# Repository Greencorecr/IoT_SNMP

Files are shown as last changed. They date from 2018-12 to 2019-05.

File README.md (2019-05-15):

# IoT_SNMP 
Dispositivos con The Things Network para conectar a SNMP

## [Conector con MQTT](https://github.com/Greencorecr/IoT_SNMP/tree/master/software/ttn2db)

Se mantiene un daemon escuchando en la plataforma de MQTT de TheThingsNetwork, escuchando mensajes de los diferentes sensores, y guardando en una base de datos de InfluxDB en formato JSON, los valores decodificados que recibe, así como un timestamp del momento en el que recibe el mensaje.

## [Conector con SNMP](https://github.com/Greencorecr/IoT_SNMP/tree/master/software/SNMP)

Dependiendo del OID consultado, snmpd llama al conector que saca de la base de el valor del sensor, así como verificando que el timestamp no sea más viejo que 5 minutos, lo que quiere decir que el sensor ha dejado de comunicarse, en el caso en que retorna "0" como valor del sensor. Se utiliza la técnica de este [ejemplo](https://github.com/fede2cr/raspberry-pi_snmp/blob/master/snmpd-example/snmpd.conf)

## Sensores

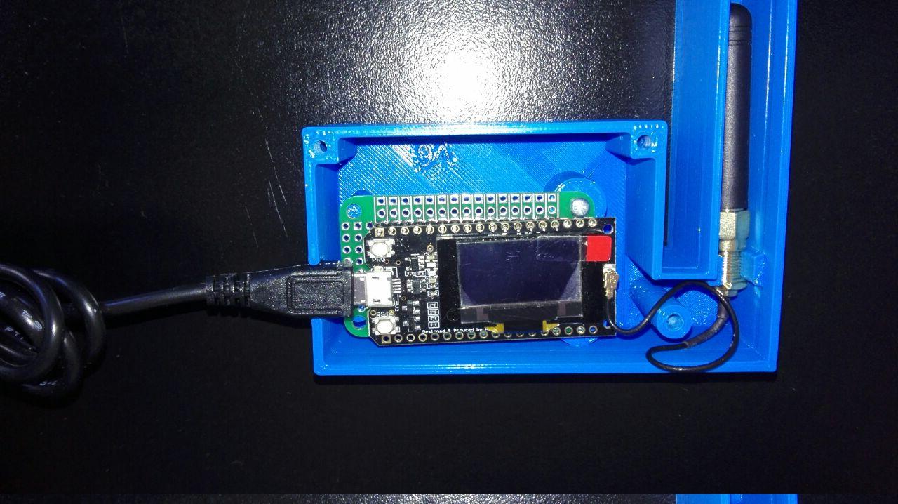
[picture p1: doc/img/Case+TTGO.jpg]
Case con TTGO


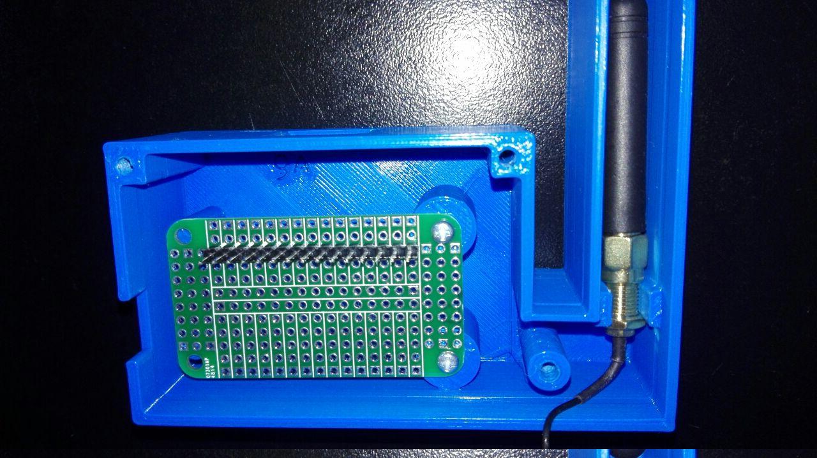
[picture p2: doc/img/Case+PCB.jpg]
Case con PCB Case con TTGO


- [Sensor de Consumo eléctrico](https://github.com/Greencorecr/IoT_SNMP/tree/master/firmware/Amperaje)
- [Sensor de Caída eléctrica](https://github.com/Greencorecr/IoT_SNMP/tree/master/firmware/Caida)
- [Sensor de Gotas](https://github.com/Greencorecr/IoT_SNMP/tree/master/firmware/Gotas)
- [Sensor de Temperatura y Humedad](https://github.com/Greencorecr/IoT_SNMP/tree/master/firmware/TempHum)
- [Sensor de Puerta](https://github.com/Greencorecr/IoT_SNMP/tree/master/firmware/Puerta)

## Arduino IDE

### Dependencias:

- Paquetes necesarios para Ubuntu

```
sudo apt update
sudo apt install -y python2 python2-pip
sudo python2 -m pip install pyserial
```

### Librerías:
- Instalar IBM LMIC framework by IBM Version 1.5.0+arduino-2

  Se debe modificar el archivo ``Arduino/libraries/IBM_LMIC_framework/src/lmic/config.h``, comentando la primera línea y descomentando la segunda:

```
  //#define CFG_eu868 1
  #define CFG_us915 1
```
- Instalar DHT sensor library for ESPx by beegee_tokyo Version 1.0.9
- Instalar U8g2 by oliver Version 2.25.10
- Instalar [Arduino_SNMP](https://github.com/fede2cr/Arduino_SNMP) en su carpera de liberías de Arduino, como puede ser ``Arduino/libraries/``
- Instalar EasyButto by Evert Arias, Version 1.0.1

### Tarjetas/Boards

- Incluir en File -> Preferences -> Additional Boards Manager URLs: ``https://dl.espressif.com/dl/package_esp32_index.json``

- Instalar en Tool -> Board -> Board Manager: esp32 by Espressif Systems

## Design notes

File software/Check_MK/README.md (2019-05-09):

# Check_MK

## Descripción

El script de python ``db2snmp.py``, lee de una base de datos InfluxDB la cual ha sido alimentada por ``ttn2db.py``, y exporta según el valor consultado en formato de SNMP. Desde el servidor de monitoreo se debe configurar un chequeo para que consulte la información de los sensores vía SNMP, y la asocie con un servicio nuevo a monitorear.

## Instrucciones de configuración

### 1. Haber realizado la configuración del conector SNMP, y que la consulta por snmpwalk retorne datos reales.

TTN_SNMP/Conectores/SNMP/README.md

### 2. Crear un script de chequeo local:

```
sudo vim /opt/omd/sites/pruebas/local/share/check_mk/checks/sensor01_humedad
```

```
#!/usr/bin/python

def inventory_sensor01_humedad(info):
   inventory = []
   for line in info:
        tipo = line[0]
        valor = line[1]
        inventory.append((tipo, valor))
   # Debug, habilitarlo únicamente para validar el check local, ya que si se deja descomentado da un error cuando Check_MK Web escanea los servicios
   #print inventory
   return inventory

def check_sensor01_humedad(item, _no_params, info):
   for line in info:
        tipo = line[0]
        valor = line[1]
        if tipo == "humedad" and valor != "0" and valor != "12336":
           infotext = "humedad actual: " + valor
           return 0, infotext, [ ("humedad", valor) ]
        else:
           infotext = "humedad actual: " + valor
           return 2, infotext, [ ("humedad", valor) ]

check_info["sensor01_humedad"] = {
    "check_function"        : check_sensor01_humedad,
    "inventory_function"    : inventory_sensor01_humedad,
    "service_description"   : "Sensor",
    "snmp_info"             : ( ".1.3.6.1.4.1.8072.1.3.2.4.1.2.16.115.101.110.115.111.114.48.49.45.104.117.109.101.100.97.100", [ "1", "2" ] ) ,
    "has_perfdata"          : True,
}
```

### 3. Agregar el host a monitorear

Se debe agregar el host a monitorear (Raspberry Pi) con la correspondiente contraseña SNMP Community y sin monitoreo por agente, con el fin de que comience a escanear servicios a nivel de SNMP únicamente.

### 4. Validar chequeo local
Una vez agregado el host, ejecutar el siguiente comando para validar el chequeo local, para lo cual es necesario convertirse en el usuario propietario del sitio a nivel de OMD, en el siguiente ejemplo se asume que el sitio de Check_MK se llama "pruebas" y el host "raspberry"

``` 
sudo su - pruebas
```

```
OMD[pruebas]:~$ check_mk -v --checks sensor01_humedad -I raspberry

Discovering services on: raspberry
raspberry:
+ FETCHING DATA
 [snmp] Execute data source
 [piggyback] Execute data source
+ EXECUTING DISCOVERY PLUGINS (1)
[(u'humedad', u'52')]
SUCCESS - Found nothing new
```

Si el comando anterior funciona correctamente e imprime los datos recolectados, ejecutamos el siguiente comando para hacer un chequeo real:

```
OMD[pruebas]:~$ cmk --no-cache -nv raspberry
Check_MK version 1.5.0p9
+ FETCHING DATA
 [snmp] Execute data source
 [piggyback] Execute data source
CPU load             OK - 15 min load 0.08
CPU utilization      OK - 5.0% used
...
...
SNMP Info            OK - Linux raspberry 4.14.79-v7+ #1159 SMP Sun Nov 4 17:50:20 GMT 2018 armv7l, raspberry, Unknown, root
Sensor humedad       OK - humedad actual: 52
...

```

En este punto el chequeo local es funcional, por lo cual desde la interfaz web de Check_MK se puede observar como un nuevo servicio monitoreado.

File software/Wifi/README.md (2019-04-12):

# WIFI

## Descripción
La siguiente guía tiene como finalidad configurar la Raspberry Pi como Access Point y servidor DHCP, con el fin de que los sensores la utilicen para conectarse de forma inalámbrica para poder tener 2 métodos de comunicación para enviar sus datos (TTN y mediante SNMP vía wifi).

## Procedimiento de configuración de Access Point con servidor DHCP sobre Raspberry Pi

1. Instalar software para Access Point y servidor DHCP

	**sudo apt install hostapd isc-dhcp-server**

2. Configurar interfaces de red:

	**sudo vim /etc/network/interfaces**
	
	```
	auto eth0
	iface eth0 inet dhcp
	
	auto wlan0
	allow-hotplug wlan0
	iface wlan0 inet static
	  address 10.42.66.1
	  netmask 255.255.255.0
	```

3. Configurar interfaz de red para el servidor DHCP

	**sudo vim /etc/default/isc-dhcp-server**
	
	```
	INTERFACESv4="wlan0"
	```

4. Configurar servidor DHCP

	**sudo vim /etc/dhcp/dhcpd.conf**
	
	```
	option domain-name "localdomain.com";
	default-lease-time 600;
	max-lease-time 7200;
	ddns-update-style none;
	authoritative;
	subnet 10.42.66.0 netmask 255.255.255.0 {
	  range 10.42.66.10 10.42.66.50;
	  option routers 10.42.66.1;
	  option domain-name-servers 1.1.1.1, 8.8.8.8;
	}
	```

5. Configurar reglas de iptables para NAT de clientes DHCP hacia Internet, mediante la interfaz cableada eth0:

	**sudo iptables -t nat -A POSTROUTING -o eth0 -j MASQUERADE**

	**sudo iptables -A FORWARD -i eth0 -o wlan0 -m state --state RELATED,ESTABLISHED -j ACCEPT**

	**sudo iptables -A FORWARD -i wlan0 -o eth0 -j ACCEPT**
	
	Ejecutar el siguiente comando y guardar reglas IPv4 únicamente:
	
	**sudo apt install iptables-persistent**

6. Habilitar reenvió de IP (IP forward) a nivel del kernel:

	**sudo vim /etc/sysctl.conf**

	```
	net.ipv4.ip_forward=1
	```

	Para aplicar el cambio sin tener que reiniciar:

	**sudo sysctl -p**

7. Configurar archivo de configuración del Access Point:

	**sudo vim /etc/default/hostapd**
	
	```
	DAEMON_CONF="/etc/hostapd/hostapd.conf"
	```

8. Configurar servicio de Access Point:

	**sudo vim /etc/hostapd/hostapd.conf**
	
	```
	ssid=<SSID>
	wpa_passphrase=<PASSWORD>
	interface=wlan0
	auth_algs=3
	channel=7
	driver=nl80211
	hw_mode=g
	logger_stdout=-1
	logger_stdout_level=2
	max_num_sta=5
	rsn_pairwise=CCMP
	wpa=2
	wpa_key_mgmt=WPA-PSK
	wpa_pairwise=TKIP CCMP
	ieee80211n=1
	ieee80211d=1
	wmm_enabled=0
	country_code=US 
	```

## Referencias

- https://learn.adafruit.com/setting-up-a-raspberry-pi-as-a-wifi-access-point/install-software
- https://edimax.freshdesk.com/support/solutions/articles/14000032146-how-to-install-ew-7811-ac600-series-and-ew-7822uac-adapters-on-raspberry-pi

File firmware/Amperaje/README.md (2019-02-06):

# Sensor de Amperaje

El sensor de amperaje utiliza una shield diseñado para Arduino, al cual le notamos algunos problemas a la hora de tratar de leerlo directamente desde una ESP32, por lo cual se decide utiliza un Arduino Nano para realizar la lectura del sensor, y luego enviar este dato vía serial hacia el ESP32 para enviar el dato a TTN.

## Arduino

Se utiliza un Arduino Nano conectado a la placa [Energy Monitor](https://www.crcibernetica.com/energy-monitor-shield-v0-2/) de CRCibernética, conectando los cuatro puertos para sensor de amperaje, a los puerto A1-A4 del Nano.

Luego empaqueta los datos y los envía por medio de una comunicación serial con el ESP32, el cual recibe del dato luego de pasar por un convertidor de lógica.

## ESP32

Una vez que el ESP32 recibe el dato, lo almacena en una variable de ambiente, preparándose para enviar dicho dato hacia la red de TTN.

## Programando

Se recomienda subir el código a ambas tarjetas, utilizar una interface serial con capacidad de 3V-5V y compruebe el envío y recepción de ambas tarjetas de forma independiente, antes de conectar el convertidor de lógica.

## ¿Como lee el amperaje?

El sensor hace el uso de Transformadores de Corriente (o **CT** por sus siglas en inglés) individuales, de tipo split-core para para medir sin necesidad de interrumpir el cable de fase, hasta un [máximo de 100A](ftp://imall.iteadstudio.com/Sensor/IM120628007/Specs_IM120628007.pdf). Para comprender un poco la teoría de los CTs puede visitar este [tutorial](https://learn.openenergymonitor.org/electricity-monitoring/ct-sensors/introduction?redirected=true). Gracias a la Ley de Ohm, también podemos calcular los Watts sobre la línea, conociendo previamente el voltaje.

## Depuración

#### Los datos enviados a TTN son "0000" en lugar de un valor real del sensor.
Esto es normal para el paquete 0, sin embargo si recibe este error de manera esporádica, y el ESP32 no se está reiniciando o reiniciando su contador de TTN; dependiendo de la frecuencia en que desee enviar los paquetes de monitoreo, se recomienda que el valor del ``delay()`` en el Arduino-Nano, no sea mayor al valor de TX_INTERVAL.

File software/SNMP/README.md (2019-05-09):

# SNMP

## Descripción

El script de python ``db2snmp.py``, lee de una base de datos InfluxDB la cual ha sido alimentada por ``ttn2db.py``, y exporta según el valor consultado en formato de SNMP. Este script está hecho para ser llamado por medio de ``snmpd``.

## Instrucciones de instalación

### venv
```
sudo python3 -m "venv" /opt/venv
sudo /opt/venv/bin/pip3 install -r requirements.txt
sudo /opt/venv/bin/python3 db2snmp.py
```

### snmpd

sudo apt install snmpd
sudo vim /etc/snmp/snmpd.conf

``` 
rocommunity strong-password

extend sensor01-humedad /opt/venv/bin/python3 /.../TTN_SNMP/Conectores/SNMP/db2snmp/sensor-01-humedad.py
```

Se debe definir una línea "extend ..." por cada sensor, para que envíe datos por SNMP, al ejecutar el script retonar un string con el nombre del sensor y el valor capturado.

Esto generará un OID especial: .1.3.6.1.4.1.8072.1.3.2.4.1.2.16.115.101.110.115.111.114.48.49.45.104.117.109.101.100.97.100

- Prefijo: .1.3.6.1.4.1.8072.1.3.2.4.1.2.
- El resto del OID se conforma por:
  1. Cantidad de caracteres de la descripción del extend, en el ejemplo "sensor01-humedad" = 16 caracteres
  2. La representación decimal ASCI de cada uno de los caracteres, en el ejemplo "sensor01-humedad":
    - 115 : ASCII decimal de 's'
    - 101 : ASCII decimal de 'e'
    - 110 : ASCII decimal de 'n'
    - 115 : ASCII decimal de 's'
    - 111 : ASCII decimal de 'o'
    - 114 : ASCII decimal de 'r'
    - 48  : ASCII decimal de '0'
    - 49  : ASCII decimal de '1'
    - 45  : ASCII decimal de '-'
    - 104 : ASCII decimal de 'h'
    - 117 : ASCII decimal de 'u'
    - 109 : ASCII decimal de 'm'
    - 101 : ASCII decimal de 'e'
    - 100 : ASCII decimal de 'd'
    - 97  : ASCII decimal de 'a'
    - 100 : ASCII decimal de 'd'

Por lo cual desde el servidor de monitoreo se puede consultar vía SNMP para confirmar que los datos se leen correctamente, para esto hay 2 formas

1. Consulta SNMP de todos los OID extendidos
``` 
snmpwalk -On  -v1 -c strong-password IP  NET-SNMP-EXTEND-MIB::nsExtendObjects
```

2. Consulta SNMP específica del OID de interés:

```
snmpwalk -On  -v1 -c strong-password IP .1.3.6.1.4.1.8072.1.3.2.4.1.2.16.115.101.110.115.111.114.48.49.45.104.117.109.101.100.97.100

.1.3.6.1.4.1.8072.1.3.2.4.1.2.16.115.101.110.115.111.114.48.49.45.104.117.109.101.100.97.100.1 = STRING: "humedad"
.1.3.6.1.4.1.8072.1.3.2.4.1.2.16.115.101.110.115.111.114.48.49.45.104.117.109.101.100.97.100.2 = STRING: "50"
```

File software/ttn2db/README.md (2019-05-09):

# MQTT

## Descripción

El script de python ``ttn2db.py`` se encarga de leer desde TTN paquetes de MQTT, e insertarlos en una base de datos de InfluxDB. Se recomienda ejecutar en conjunto con SystemD como un servicio, y es capaz de escuchar varios sensores de forma simultánea, agregando sus datos en la base de datos según el tipo de sensor.

## Instrucciones de instalación

```
sudo python3 -m "venv" /opt/venv
sudo /opt/venv/bin/pip3 install -r requirements.txt
sudo /opt/venv/bin/python3 influxdb-init.py
sudo /opt/venv/bin/python3 ttn2db.py
sudo apt install influxdb
```

## Configuración de servicio a nivel de Systemd

1. Crear script de systemd:

    vim /etc/systemd/system/ttn2db.service

    ```
    [Unit]
    Description= loads data from TTN and save it in a local InfluxDB file in json format
    After=syslog.target

    [Service]
    Type=simple
    User=root
    Group=root
    Environment="PYTHONUNBUFFERED=1"
    ExecStart=/opt/venv/bin/python3 /opt/MQTT/ttn2db.py
    StandardOutput=syslog
    StandardError=syslog
    SyslogIdentifier=ttn2db
    Restart=always

    [Install]
    WantedBy=multi-user.target
    ```

2. Aplicar los cambios:

    ```
    sudo systemctl daemon-reload
    sudo systemctl enable ttn2db
    sudo systemctl start ttn2db
    ```

3. Para crear un archivo de log personalizado:

    - Crear el archivo /etc/rsyslog.d/ttn2db.conf:

        ```
        if $programname == 'ttn2db' then /var/log/ttn2db.log

        ```
    - Reiniciar el servicio para aplicar cambios:
        ``` 
        sudo systemctl restart rsyslog.service
        ```

    - Confirmar el correcto funcionamiento visualizando el log:
        sudo tail -f /var/log/ttn2db.log

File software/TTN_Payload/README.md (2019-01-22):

# TTN Payload

Necesita agregar un decodificador de ``payload`` dentro de la consola de TTN, siguiendo este tutorial de [Adafruit](https://learn.adafruit.com/the-things-network-for-feather/payload-decoding).

Utilice el archivo ``decoder.js`` como base.

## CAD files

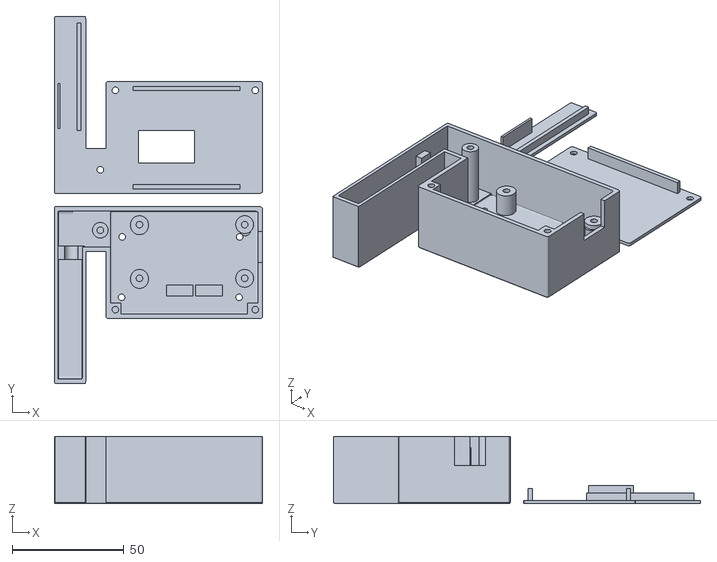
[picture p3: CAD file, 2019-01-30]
hardware/3D/sensor-05-caida.stl
93.0 x 164.0 x 30.0

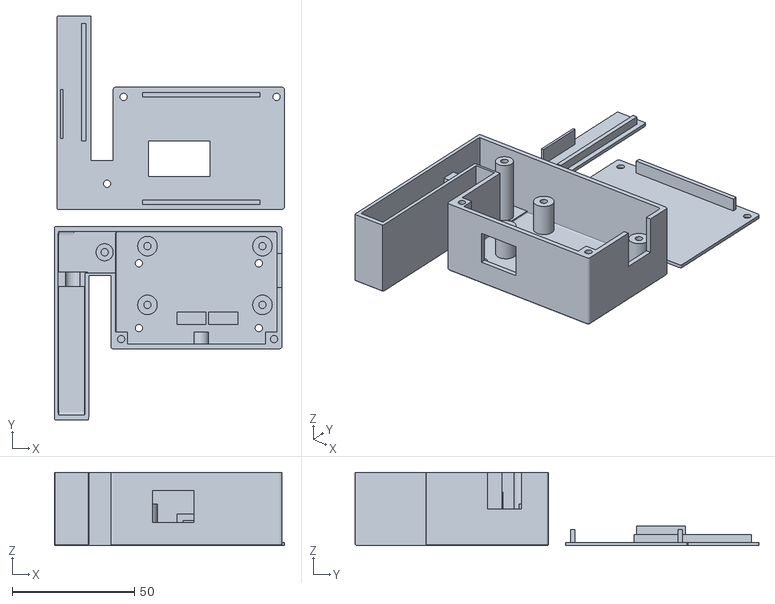
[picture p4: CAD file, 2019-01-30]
hardware/3D/sensor-01-temperatura-humedad.stl
94.0 x 165.0 x 30.0

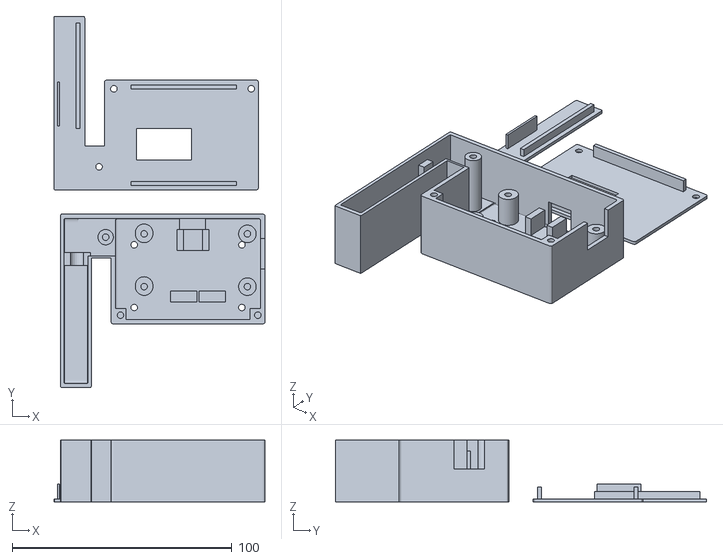
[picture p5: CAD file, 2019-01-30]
hardware/3D/sensor-02-puerta.stl
96.0 x 169.0 x 28.0

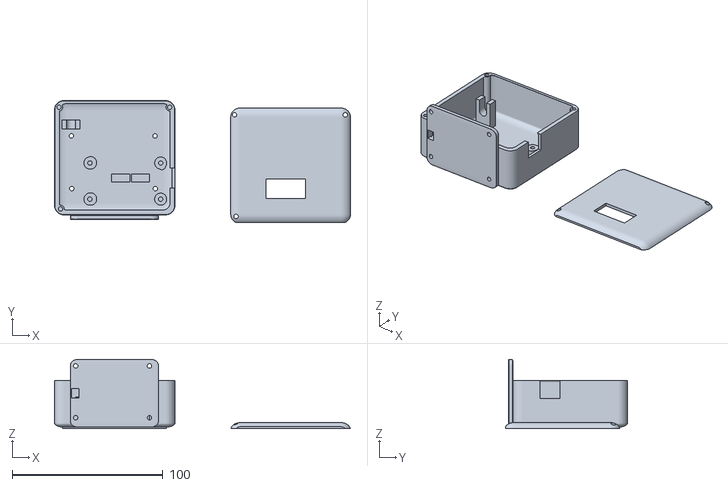
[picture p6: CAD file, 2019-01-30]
hardware/3D/sensor-03-gotas.stl
196.6 x 81.0 x 46.0

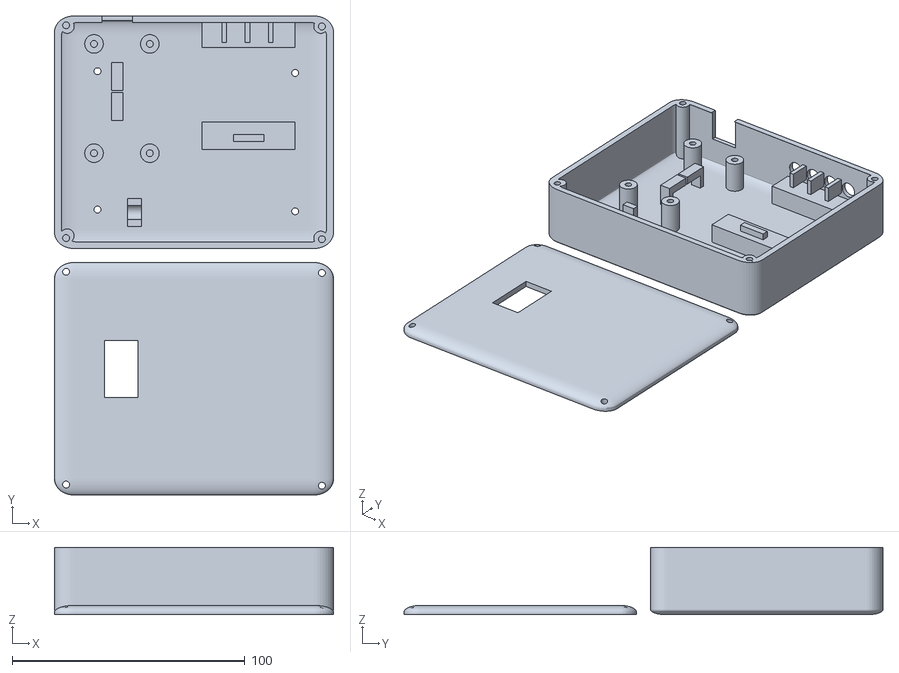
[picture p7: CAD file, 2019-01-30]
hardware/3D/sensor-04-consumo.stl
120.0 x 206.0 x 29.0

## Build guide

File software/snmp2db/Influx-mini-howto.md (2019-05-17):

# InfluxDB Mini Howto

Para depurar y desarrollar con influxdb es importante conocer algunos comandos básicos en dos tipos de clientes.

## InfluxDB Client

```
sudo apt install influxdb-client
influx
```
```sql
> show databases;

> select last(*) from measures;
ERR: database name required

> use sensores;

> show measurements

> select Last(*) from sensorgotas

> drop measurement sensoramps

```

## Python

Puede crear un archivo con este código, o también escribir desde una terminal:

```
from influxdb import InfluxDBClient

# InfluxDB
influxHost='localhost'
influxPort=8086
influxUser = 'root'
influxPassword = 'root'
influxDbname = 'sensores'
influxDbuser = 'greencore'
influxClient = InfluxDBClient(influxHost, influxPort, influxUser, influxPassword, influxDbname)

json_body = [{'measurement': 'sensorXXX',...

influxClient.write_points(json_body)
```

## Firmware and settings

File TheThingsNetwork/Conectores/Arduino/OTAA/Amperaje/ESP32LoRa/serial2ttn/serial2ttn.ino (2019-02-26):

/*
 * Sensor de consumo eléctrico
 * Para ESP32 TTGOv2
 * por Greencore Solutions
 * Usa serial2 y empaqueta hacia TTN
 * 
 * Debe definir APPEUI, DEVEUI, APPKEY
 */


#include <lmic.h>
#include <hal/hal.h>
#include <SPI.h>
#include <Wire.h>
#include<U8g2lib.h>
#include<Arduino.h>


// Imagen de GreenCore 50x50 px
#define greenfoot_width 50
#define greenfoot_height 50
static const unsigned char greenfoot_bits[] PROGMEM = {
   0x00, 0x00, 0x00, 0x00, 0x00, 0x00, 0x00, 0xfc, 0xff, 0xff, 0xff, 0xff,
   0xff, 0x00, 0xfe, 0xff, 0xff, 0xff, 0xff, 0xff, 0x01, 0xff, 0xff, 0xff,
   0xff, 0xff, 0xff, 0x03, 0xff, 0xff, 0xff, 0xff, 0xff, 0xff, 0x03, 0xff,
   0xff, 0xff, 0xff, 0xff, 0xff, 0x03, 0xff, 0xff, 0xff, 0xff, 0xff, 0xff,
   0x03, 0xff, 0xff, 0xff, 0x7f, 0xf0, 0xff, 0x03, 0xff, 0xc0, 0xff, 0x3f,
   0xe0, 0xff, 0x03, 0x7f, 0xc0, 0xff, 0x1f, 0xc0, 0xff, 0x03, 0x3f, 0x80,
   0xff, 0x0f, 0xc0, 0xff, 0x03, 0x3f, 0x80, 0xff, 0x0f, 0xc0, 0xff, 0x03,
   0x3f, 0x80, 0xff, 0x0f, 0xc0, 0xff, 0x03, 0x3f, 0x00, 0xff, 0x0f, 0xc0,
   0xff, 0x03, 0x3f, 0x80, 0xff, 0x0f, 0xc0, 0xff, 0x03, 0x7f, 0x80, 0xff,
   0x07, 0xc0, 0xff, 0x03, 0x7f, 0xc0, 0xff, 0x07, 0xe0, 0xff, 0x03, 0x7f,
   0xe0, 0xff, 0x03, 0xf8, 0xff, 0x03, 0xff, 0xe1, 0xff, 0x81, 0xff, 0xff,
   0x03, 0xff, 0xf1, 0xff, 0xc0, 0xff, 0xff, 0x03, 0xff, 0xf3, 0x7f, 0xe0,
   0xff, 0xff, 0x03, 0xff, 0xe3, 0x7f, 0xf0, 0xff, 0xff, 0x03, 0xff, 0xe3,
   0x3f, 0xf8, 0xff, 0xff, 0x03, 0xff, 0xe7, 0x1f, 0xfc, 0xff, 0xff, 0x03,
   0xff, 0xc7, 0x0f, 0xfe, 0xff, 0xff, 0x03, 0xff, 0xc7, 0x07, 0xff, 0xff,
   0xff, 0x03, 0xff, 0x87, 0x83, 0xff, 0xff, 0xff, 0x03, 0xff, 0x07, 0xc0,
   0xff, 0xff, 0xff, 0x03, 0xff, 0x07, 0xc0, 0xff, 0xff, 0xff, 0x03, 0xff,
   0x07, 0xe0, 0xff, 0x1f, 0xfc, 0x03, 0xff, 0x07, 0xe0, 0xff, 0x07, 0xf8,
   0x03, 0xff, 0x03, 0xf0, 0xff, 0x07, 0xf0, 0x03, 0xff, 0x03, 0xf0, 0xff,
   0x03, 0xf0, 0x03, 0xff, 0x01, 0xf0, 0xff, 0x01, 0xf0, 0x03, 0xff, 0x00,
   0xe0, 0xff, 0x00, 0xf0, 0x03, 0xff, 0x00, 0x80, 0x1f, 0x00, 0xf0, 0x03,
   0x7f, 0x00, 0x00, 0x00, 0x00, 0xf0, 0x03, 0x3f, 0x00, 0x00, 0x00, 0x00,
   0xf8, 0x03, 0x1f, 0x00, 0x00, 0xe0, 0x0f, 0xfc, 0x03, 0x0f, 0x00, 0x00,
   0xfe, 0x1f, 0xfe, 0x03, 0x07, 0x00, 0xe0, 0xff, 0xff, 0xff, 0x03, 0x03,
   0x00, 0xf8, 0xff, 0xff, 0xff, 0x03, 0x01, 0x00, 0xfe, 0xff, 0xff, 0xff,
   0x03, 0x00, 0x00, 0xff, 0xff, 0xff, 0xff, 0x03, 0x00, 0xc0, 0xff, 0xff,
   0xff, 0xff, 0x03, 0x00, 0xe0, 0xff, 0xff, 0xff, 0xff, 0x03, 0x00, 0xf0,
   0xff, 0xff, 0xff, 0xff, 0x03, 0x00, 0xf8, 0xff, 0xff, 0xff, 0xff, 0x01,
   0x00, 0xf8, 0xff, 0xff, 0xff, 0xff, 0x01, 0x00, 0xfc, 0xff, 0xff, 0xff,
   0xff, 0x00 };

static const u1_t PROGMEM DEVEUI[8]={ } ; // Device EUI, hex, lsb
void os_getDevEui (u1_t* buf) { memcpy_P(buf, DEVEUI, 8);}

static const u1_t PROGMEM APPEUI[8]={ }; // Application EUI, hex, lsb
void os_getArtEui (u1_t* buf) { memcpy_P(buf, APPEUI, 8);}

static const u1_t PROGMEM APPKEY[16] = { }; // App Key, hex, msb
void os_getDevKey (u1_t* buf) {  memcpy_P(buf, APPKEY, 16);}


U8G2_SSD1306_128X64_NONAME_F_SW_I2C u8g2(U8G2_R0, /* clock=*/ 15, /* data=*/ 4, /* reset=*/ 16); 

unsigned long previousMillis = 0;
const long interval = 300000;
unsigned int paqCont = 0;
uint8_t mydata[] = "00000000000000000";

// Para lectura de Serial2
String inputString = "";      // a String to hold incoming data
bool stringComplete = false;  // whether the string is complete

static osjob_t sendjob;

// Schedule TX every this many seconds (might become longer due to duty
// cycle limitations).
const unsigned TX_INTERVAL = 60;

// Pin mapping
const lmic_pinmap lmic_pins = {
    .nss = 18,
    .rxtx = LMIC_UNUSED_PIN,
    .rst = 14,
    .dio = {26, 33, 32}  // Pins for the Heltec ESP32 Lora board/ TTGO Lora32 with 3D metal antenna
};


void(* resetFunc) (void) = 0; //declare reset function @ address 0

void logo(){
    // LOGO
    u8g2.clearBuffer();
    u8g2.clearDisplay();
    u8g2.setFont(u8g2_font_ncenB08_tr);
    u8g2.drawXBMP(39,0,50,50,greenfoot_bits);
    u8g2.drawStr(5,64,"GreenCore Solutions");
    u8g2.sendBuffer();
}

void onEvent (ev_t ev) {
    Serial.print(os_getTime());
    Serial.print(": ");
    switch(ev) {
        case EV_SCAN_TIMEOUT:
            Serial.println(F("EV_SCAN_TIMEOUT"));
            break;
        case EV_BEACON_FOUND:
            Serial.println(F("EV_BEACON_FOUND"));
            break;
        case EV_BEACON_MISSED:
            Serial.println(F("EV_BEACON_MISSED"));
            break;
        case EV_BEACON_TRACKED:
            Serial.println(F("EV_BEACON_TRACKED"));
            break;
        case EV_JOINING:
            Serial.println(F("EV_JOINING"));
            break;
        case EV_JOINED:
            Serial.println(F("EV_JOINED"));
            LMIC_setLinkCheckMode(0);
            break;
        case EV_RFU1:
            Serial.println(F("EV_RFU1"));
            break;
        case EV_JOIN_FAILED:
            Serial.println(F("EV_JOIN_FAILED"));
            break;
        case EV_REJOIN_FAILED:
            Serial.println(F("EV_REJOIN_FAILED"));
            break;
            break;
        case EV_TXCOMPLETE:
            Serial.println(F("EV_TXCOMPLETE (includes waiting for RX windows)"));
            if(LMIC.dataLen) {
                // data received in rx slot after tx
                Serial.print(F("Data Received: "));
                Serial.write(LMIC.frame+LMIC.dataBeg, LMIC.dataLen);
                Serial.println();
            }
            // Schedule next transmission
            os_setTimedCallback(&sendjob, os_getTime()+sec2osticks(TX_INTERVAL), do_send);
            break;
        case EV_LOST_TSYNC:
            Serial.println(F("EV_LOST_TSYNC"));
            break;
        case EV_RESET:
            Serial.println(F("EV_RESET"));
            break;
        case EV_RXCOMPLETE:
            // data received in ping slot
            Serial.println(F("EV_RXCOMPLETE"));
            break;
        case EV_LINK_DEAD:
            Serial.println(F("EV_LINK_DEAD"));
            break;
        case EV_LINK_ALIVE:
            Serial.println(F("EV_LINK_ALIVE"));
            break;
         default:
            Serial.println(F("Unknown event"));
            break;
    }
}

void do_send(osjob_t* j){
    unsigned int sensorCount = 0;
    String sensorData[4] = "0000";
    // LOGO
    logo();
    delay(1000); // muestra el logo por 5 segundos  

    // TODO: Mover a funcion
    while (Serial2.available()) {
      // get the new byte:
      char inChar = (char)Serial2.read();
      // add it to the inputString:
      if (inChar == ':') {
        sensorData[sensorCount] = inputString;
        inputString="";
        sensorCount++;        
      } else if (inChar == '\n') {
        sensorData[3]= inputString;
        Serial.print("sensorData[0]: ");
        Serial.println(sensorData[0]);
        Serial.print("sensorData[1]: ");
        Serial.println(sensorData[1]);
        Serial.print("sensorData[2]: ");
        Serial.println(sensorData[2]);
        Serial.print("sensorData[3]: ");
        Serial.println(sensorData[3]); 
        inputString = "";
        stringComplete = true;
        sensorCount = 0;
      } else {
        inputString += inChar;
      }
    } 

    // Creando paquete para sensor0-3
    int tempInteger = sensorData[0].toInt();
    mydata[1] = highByte(tempInteger);
    mydata[2] = lowByte(tempInteger);
    float tempFloat = (sensorData[0].toFloat() - tempInteger) * 100;
    tempInteger = int(tempFloat);
    mydata[3] = highByte(tempInteger);
    mydata[4] = lowByte(tempInteger);

    tempInteger = sensorData[1].toInt();
    mydata[5] = highByte(tempInteger);
    mydata[6] = lowByte(tempInteger);
    tempFloat = (sensorData[1].toFloat() - tempInteger) * 100;
    tempInteger = int(tempFloat);
    mydata[7] = highByte(tempInteger);
    mydata[8] = lowByte(tempInteger);

    tempInteger = sensorData[2].toInt();
    mydata[9] = highByte(tempInteger);
    mydata[10] = lowByte(tempInteger);
    tempFloat = (sensorData[2].toFloat() - tempInteger) * 100;
    tempInteger = int(tempFloat);
    mydata[11] = highByte(tempInteger);
    mydata[12] = lowByte(tempInteger);

    tempInteger = sensorData[3].toInt();
    mydata[13] = highByte(tempInteger);
    mydata[14] = lowByte(tempInteger);
    tempFloat = (sensorData[3].toFloat() - tempInteger) * 100;
    tempInteger = int(tempFloat);
    mydata[15] = highByte(tempInteger);
    mydata[16] = lowByte(tempInteger);



    unsigned long currentMillis = millis();
    
    // Check if there is not a current TX/RX job running
    if (LMIC.opmode & OP_TXRXPEND) {
        Serial.println(F("OP_TXRXPEND, not sending"));
    } else {
           // Prepare upstream data transmission at the next possible time.
           LMIC_setTxData2(1, mydata, sizeof(mydata)-1, 0);
        }
    Serial.println(F("Packet queued"));
    Serial.println(LMIC.freq);

 // INFORMACIÓN GENERAL
    char frecString[10]; 
    dtostrf(LMIC.freq/1000000.0,3,2,frecString);
    char paqString02[10]; 
    dtostrf(paqCont,2,0,paqString02);
    u8g2.clearBuffer();
    u8g2.clearDisplay();
    u8g2.setFont(u8g2_font_ncenB08_tr);
    u8g2.drawStr(0, 10, "Consumo Eléctrico");
    u8g2.drawStr(0, 20, "Frecuencia: ");
    u8g2.drawStr(68,20,frecString);
    u8g2.drawStr(100,20," MHz");
    u8g2.drawStr(0,30,"Paquete: ");
    u8g2.drawStr(50,30,paqString02);

    u8g2.drawStr(0,40,"s1: ");
    u8g2.drawStr(60,40,"s2: ");
    u8g2.drawStr(0,50,"s3: ");
    u8g2.drawStr(60,50,"s4: ");

    char sensorData0[5];
    char sensorData1[5];
    char sensorData2[5];
    char sensorData3[5];
    sensorData[0].toCharArray(sensorData0, 5);
    sensorData[1].toCharArray(sensorData1, 5);
    sensorData[2].toCharArray(sensorData2, 5);
    sensorData[3].toCharArray(sensorData3, 5);
    u8g2.drawStr(30,40,sensorData0);
    u8g2.drawStr(90,40,sensorData1);
    u8g2.drawStr(30,50,sensorData2);
    u8g2.drawStr(90,50,sensorData3);

    u8g2.sendBuffer();
    paqCont++;
}

void setup() {
    Serial2.begin(115200); // Desde Arduino-Nano
    Serial.begin(115200);
    Serial.println(F("Starting"));
    u8g2.begin();
    #ifdef VCC_ENABLE
    // For Pinoccio Scout boards
    pinMode(VCC_ENABLE, OUTPUT);
    digitalWrite(VCC_ENABLE, HIGH);
    delay(1000);
    #endif

    // LMIC init
    os_init();
    // Reset the MAC state. Session and pending data transfers will be discarded.
    LMIC_reset();
    LMIC_selectSubBand(1);
    //Disable FSB2-8, channels 16-72
    for (int i = 16; i < 73; i++) {
      if (i != 10)
        LMIC_disableChannel(i);
  
    }
    LMIC_setClockError(MAX_CLOCK_ERROR * 1 / 100);

    // tipo de sensor
    mydata[0] = 0x01;

    // Start job
    do_send(&sendjob);
}

void loop() {
  os_runloop_once();
}

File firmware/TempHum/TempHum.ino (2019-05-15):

/*
 * Sensor de temperatura y humedad
 * Para ESP32 TTGOv2
 * por Greencore Solutions
 * Usa pin 25 para leer al DHT11
 * 
 */


#include <lmic.h>
#include <hal/hal.h>
#include <SPI.h>
#include <Wire.h>
#include "DHTesp.h"
#include "Ticker.h"
#include<U8g2lib.h>
#include<Arduino.h>
#include <WiFi.h>
#include <ESPmDNS.h>
#include <WiFiUdp.h>
#include <Arduino_SNMP.h>


#include "config.h"

#ifdef USE_IAS
#define COMPDATE __DATE__ __TIME__
#define MODEBUTTON 0

#include <IOTAppStory.h>
IOTAppStory IAS(COMPDATE, MODEBUTTON);
#endif

U8G2_SSD1306_128X64_NONAME_F_SW_I2C u8g2(U8G2_R0, /* clock=*/ 15, /* data=*/ 4, /* reset=*/ 16); 

WiFiUDP udp;
SNMPAgent snmp = SNMPAgent("greencore");  // Starts an SMMPAgent instance with the community string 'public'

int snmpTemp = 0;
int snmpHum = 0;


unsigned long previousMillis = 0;
const long interval = 300000;
unsigned int paqCont = 0;
uint8_t mydata[] = "00000";
static osjob_t sendjob;

DHTesp dht;

void tempTask(void *pvParameters);
bool getTemperature();
void triggerGetTemp();

/** Task handle for the light value read task */
TaskHandle_t tempTaskHandle = NULL;
/** Ticker for temperature reading */
Ticker tempTicker;
/** Comfort profile */
ComfortState cf;
/** Flag if task should run */
bool tasksEnabled = false;
/** Pin number for DHT11 data pin */
int dhtPin = 25;

void logo(){
    // LOGO
    u8g2.clearBuffer();
    u8g2.clearDisplay();
    u8g2.setFont(u8g2_font_ncenB08_tr);
    u8g2.drawXBMP(39,0,50,50,greenfoot_bits);
    u8g2.drawStr(5,64,"GreenCore Solutions");
    u8g2.sendBuffer();
}

bool initTemp() {
  byte resultValue = 0;
  // Initialize temperature sensor
  dht.setup(dhtPin, DHTesp::DHT11);
  Serial.println("DHT initiated");

  // Start task to get temperature
  xTaskCreatePinnedToCore(
      tempTask,                       /* Function to implement the task */
      "tempTask ",                    /* Name of the task */
      4000,                           /* Stack size in words */
      NULL,                           /* Task input parameter */
      5,                              /* Priority of the task */
      &tempTaskHandle,                /* Task handle. */
      1);                             /* Core where the task should run */

  if (tempTaskHandle == NULL) {
    Serial.println("Failed to start task for temperature update");
    return false;
  } else {
    // Start update of environment data every 10 seconds
    tempTicker.attach(10, triggerGetTemp);
  }
  return true;
}

void triggerGetTemp() {
  if (tempTaskHandle != NULL) {
     xTaskResumeFromISR(tempTaskHandle);
  }
}

void tempTask(void *pvParameters) {
  Serial.println("tempTask loop started");
  while (1) // tempTask loop
  {
    if (tasksEnabled) {
      // Get temperature values
      getTemperature();
    }
    // Got sleep again
    vTaskSuspend(NULL);
  }
}

bool getTemperature() {
  // Reading temperature for humidity takes about 250 milliseconds!
  // Sensor readings may also be up to 2 seconds 'old' (it's a very slow sensor)
  TempAndHumidity newValues = dht.getTempAndHumidity();
  // Check if any reads failed and exit early (to try again).
  if (dht.getStatus() != 0) {
    Serial.println("DHT11 error status: " + String(dht.getStatusString()));
    return false;
  }

  Serial.println(" T:" + String(newValues.temperature) + " H:" + String(newValues.humidity));
  
  // DATOS DEL SENSOR
  u8g2.clearBuffer();
  u8g2.clearDisplay();
  u8g2.setFont(u8g2_font_ncenB24_tr);
  char tempString[3];
  char humString[3];
  dtostrf(newValues.temperature,3,0,tempString);
  dtostrf(newValues.humidity,3,0,humString);
  u8g2.drawStr(5,44,tempString);
  u8g2.drawStr(69,44,humString);
  u8g2.sendBuffer();

  mydata[1] = highByte((int) newValues.temperature);
  mydata[2] = lowByte((int) newValues.temperature);
  mydata[3] = highByte((int) newValues.humidity);
  mydata[4] = lowByte((int) newValues.humidity);

  snmpTemp = newValues.temperature;
  snmpHum = newValues.humidity;

  return true;
}


void(* resetFunc) (void) = 0; //declare reset function @ address 0

void onEvent (ev_t ev) {
    Serial.print(os_getTime());
    Serial.print(": ");
    switch(ev) {
        case EV_SCAN_TIMEOUT:
            Serial.println(F("EV_SCAN_TIMEOUT"));
            break;
        case EV_BEACON_FOUND:
            Serial.println(F("EV_BEACON_FOUND"));
            break;
        case EV_BEACON_MISSED:
            Serial.println(F("EV_BEACON_MISSED"));
            break;
        case EV_BEACON_TRACKED:
            Serial.println(F("EV_BEACON_TRACKED"));
            break;
        case EV_JOINING:
            Serial.println(F("EV_JOINING"));
            break;
        case EV_JOINED:
            Serial.println(F("EV_JOINED"));
            LMIC_setLinkCheckMode(0);
            break;
        case EV_RFU1:
            Serial.println(F("EV_RFU1"));
            break;
        case EV_JOIN_FAILED:
            Serial.println(F("EV_JOIN_FAILED"));
            break;
        case EV_REJOIN_FAILED:
            Serial.println(F("EV_REJOIN_FAILED"));
            break;
            break;
        case EV_TXCOMPLETE:
            Serial.println(F("EV_TXCOMPLETE (includes waiting for RX windows)"));
            if(LMIC.dataLen) {
                // data received in rx slot after tx
                Serial.print(F("Data Received: "));
                Serial.write(LMIC.frame+LMIC.dataBeg, LMIC.dataLen);
                Serial.println();
            }
            // Schedule next transmission
            os_setTimedCallback(&sendjob, os_getTime()+sec2osticks(TX_INTERVAL), do_send);
            break;
        case EV_LOST_TSYNC:
            Serial.println(F("EV_LOST_TSYNC"));
            break;
        case EV_RESET:
            Serial.println(F("EV_RESET"));
            break;
        case EV_RXCOMPLETE:
            // data received in ping slot
            Serial.println(F("EV_RXCOMPLETE"));
            break;
        case EV_LINK_DEAD:
            Serial.println(F("EV_LINK_DEAD"));
            break;
        case EV_LINK_ALIVE:
            Serial.println(F("EV_LINK_ALIVE"));
            break;
         default:
            Serial.println(F("Unknown event"));
            break;
    }
}
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

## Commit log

2018-12-26 Agregando sensor de goteo
2018-12-26 Agregando Puerta, cambiando delay en Gotas y mejorando documentación de config
2018-12-26 Actualizando README con nuevos sensores
2018-12-27 Se arreglan erroes de md
2018-12-27 Se arregla nombre de aplicación
2018-12-28 Travis: Agregando python3 a la prueba unitaria
2018-12-28 Travis: Modificando nombre de test.py
2018-12-28 Agregando ícono de travis al README
2018-12-28 Travis: Agregando tinydb a test.py de SNMP
2018-12-28 Cambiando nombre de sensor para travis
2018-12-28 Se agregan detalles de dependencias para Arduino IDE.
2019-01-10 Caida electrica funcional, requiere ajustes antes de poner en produccion. Demo de pantalla de inicio.
2019-01-10 Correccion en directorio sensor Caida.
2019-01-18 Conector para Check_MK y ajustes en conector SNMP
2019-01-22 Agregando decoder para payload de TTN
2019-01-23 Version inicial de ESP32-Arduino para Sensor de Amperaje
2019-01-29 Chequeos locales para cada sensor
2019-01-29 Se ordena la estructura y se actualizan conectores.
2019-01-30 Se corrije estructura eliminando directorio Sensores ya que se había pasado a Conectores. Se actualiza código de T+H y Puerta con interfaz nueva.
2019-01-30 Cases 3D
    [sensor-01-temperatura-humedad.stl, sensor-02-puerta.stl, sensor-03-gotas.stl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]
2019-01-31 Agregando código de Amperaje/Arduino-Nano
2019-02-01 Interfaz nueva, solo falta el de consumo.
2019-02-01 Script systemd para ttn2db
2019-02-01 Se agrega comando para habilitar servicio systemd
2019-02-04 Version completa de energy2serial.ino
2019-02-04 Version con problemas para imprimir datos de sensor en pantalla de serial2ttn.ino
    [serial2ttn.ino]
2019-02-04 Moviendo serial2ttn a ESP32LoRa
2019-02-04 Actualizando Payload decoder.js para enviar datos de sensor de consumo electrico
2019-02-04 Version para producción de serial2ttn
2019-02-05 Agregando depuración para el sensor de Amperaje en el README
2019-02-05 Re-ordenando para mismo orden de payload decoder, agregando código para amperaje
2019-02-06 Agregando documentación sobre CTs para sensor de amperaje
2019-02-14 Agregando version inicial de Wifi local
2019-02-15 Wifi: Agregando soporte para pantalla, quitando servidor web, agregando config.h
2019-02-25 Codigo OTAA Gotas, T+H, Amperaje Se agrega delay 1s para logo e informacion general, el resto de delays se quitan
2019-02-26 Se mejoran los print para que muestren informacion detallada de los sensores. Se agrega información RSSI, SNR, Channel y SF
2019-02-27 Correccion en captura de SF
2019-02-27 Primer cambio para unificar OTAA y ABP. Listo Caida
2019-02-28 Modificando resto de sensores para ABP/OTAA
2019-03-05 Deshabilitando unitests para su reescritura
2019-03-05 Agregando rutas para Travis
2019-03-06 Agregando wifi y mdns a resto de sensores ESP32
2019-03-06 Arreglando ícono de Travis en README.md
2019-03-07 Se separan bases de datos de TinyDB para solucionar error de chequeo UNKNOWN
2019-03-07 Agregando libreria SNMP a README, agregando funcionalidad de snmp a sensor de Puerta
2019-03-08 Typo en URL de README
2019-03-15 Se agrega descripción de tipo de sensor en información de SNMP
2019-03-20 Agregando IAS, modificando a non-blocking, mejorando refrescamiento de pantalla
2019-03-21 Haciendo IAS opcional por medio de USE_IAS
2019-03-27 Conectores/MQTT: Agregando cambios para influxdb
2019-03-27 Modificando payload decoder para nuevo formato de puerta
2019-03-27 Cambios para IAS, y contador de puerta
2019-03-28 Agregando IAS a resto de firmware para ESP32
2019-03-29 Eliminando refreshDisplay de Caida.ino
2019-03-31 Ya funciona en sensor de puerta, detectar si está abierta o no, agregado a funcion de snmp y a paquete de lora
2019-03-31 En sensor de puerta, mejor conteo de eventos, ignorando cantidad de keypresses sin debounce
2019-03-31 Agregando SNMP a sensor de Gotas
2019-04-01 Agregando SNMP a versión de caída, mejorando resolución de lectura
2019-04-01 Agregando código inicial de SNMP a sensor de amperaje
2019-04-02 Moviendo sensor-01-humedad en SNMP/ hacia influxdb
2019-04-03 Agregando cambios en requirements.txt de SNMP
2019-04-05 Agregando validación de TTN o SNMP a sensor-01-humedad
2019-04-05 Agregando validación de TTN o SNMP a sensor-01-humedad, eliminando If de prueba
2019-04-05 Agregando script para inicializar base de datos influxdb
2019-04-09 Unificando SNMP/sensor-nn-tipo.py en un solo script
2019-04-10 Limpiando SNMP/ de scripts individuales
2019-04-12 Guía de configuración de AP y DHCP sobre Raspberry Pi
2019-04-12 Comando para inicializar influxdb
2019-04-23 Instalación de cliente Influx sobre Raspbian
2019-04-30 Restructura de directorios, gitignore de binarios, pruebas de URL roto en README
    [sensor-01-temperatura-humedad.stl, sensor-02-puerta.stl, sensor-03-gotas.stl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]
2019-04-30 Cambio de paths de requirements
2019-04-30 Agregando pruebas de md en todo el repo
2019-04-30 Moviendo ttn2db a formato de proyecto de python, para unittest. Agregando unittests para import
2019-04-30 Arreglando path para pruebas travis
2019-05-01 Cambiando ejecucion de find para retornar error si encuentra links muertos
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2019-05-02 Agregando sonar a travis. Org correcta
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2019-05-02 Quitando codigo de Arduino (C) de Sonar de forma temporal
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2019-05-08 sensor.py: errorIndication debe ser un string para concatenarse
2019-05-08 Hice commit con error de syntax en snmp2db. Arreglando
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2019-05-09 Corrección de README's (TinyDB -> InfluxDB) Corrección OID puerta, usar Open en lugar de Count
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2019-05-09 Cambiando tipos de datos a int() para quedar igual que TTN
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2019-05-09 Arreglando manejor de variable hum
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2019-05-13 Agregando libreria de Easy Button, a firmware de Puerta
2019-05-14 Arreglando codigo de sensor de puerta, con Open y Count
    [Puerta.ino]
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
